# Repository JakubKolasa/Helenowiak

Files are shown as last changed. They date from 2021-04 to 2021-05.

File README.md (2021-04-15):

# Helenowiak
Projekt zakłada stworzenie robota od podstaw. Logika robota będzie oparta na mikrokontrolerze STM32. Zostanie on umieszczony na zaprojektowanej w programie KiCad płytce PCB. Model robota został zaprojektowany w programie AutoCAD Inventor.  Do detekcji przeciwnika wykorzystane zostaną czujniki zbliżeniowe działające w zakresie podczerwieni. W celu zastosowania bardziej skomplikowanych algorytmów walki i umożliwienia swobodnego poruszania się po dojo, robot zostanie wyposażony w czujniki odbiciowe mające na celu wykryć krawędzie areny, oraz enkodery umożliwiające dokładny pomiar przebytej odległości. Robot będzie komunikował się z komputerem poprzez moduł bluetooth dzięki czemu będzie można sterować nim w sposób zdalny przy pomocy odpowiednich komend.

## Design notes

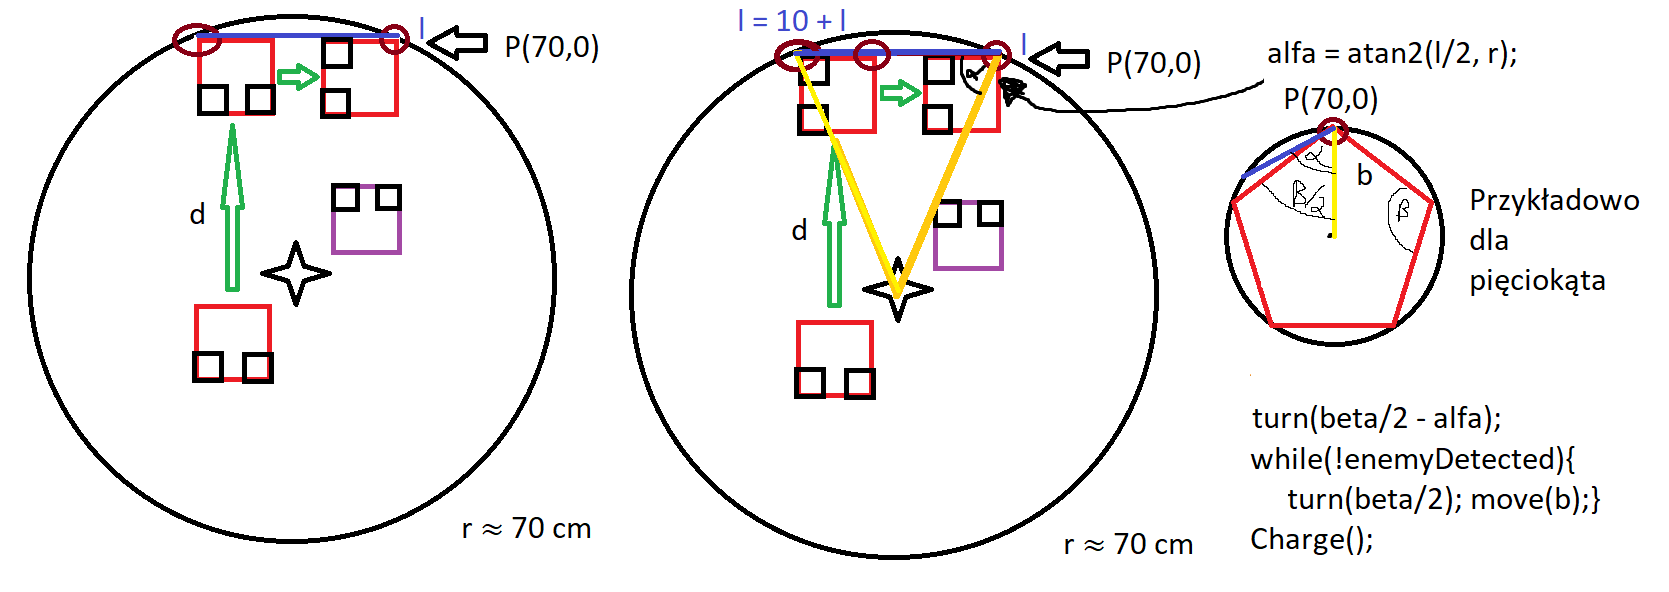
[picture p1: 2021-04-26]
Algorytm.png

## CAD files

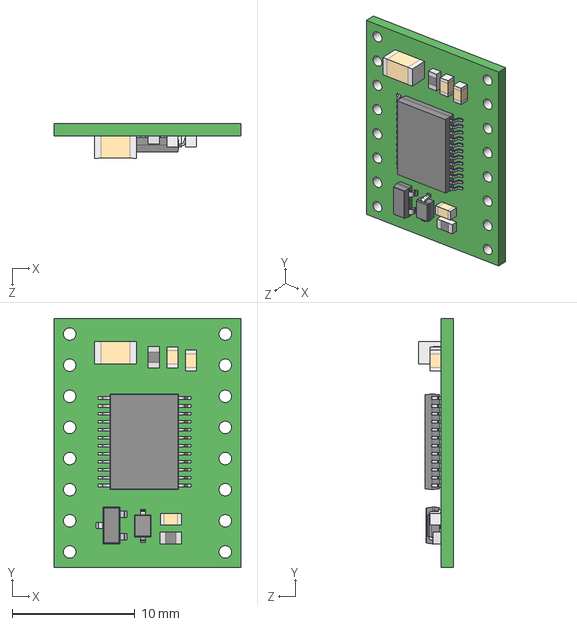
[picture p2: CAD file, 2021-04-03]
Helenowiak_mechanika/tb6612fng-dual-motor-driver-carrier.step
15.2 x 20.3 x 2.82 mm

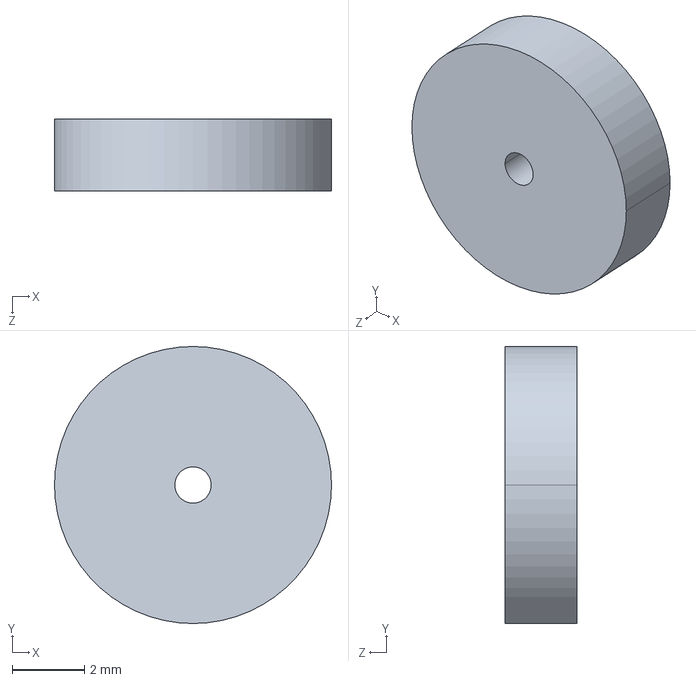
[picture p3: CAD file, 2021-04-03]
Helenowiak_mechanika/magnetic-encoder-pair-kit-for-micro-metal-gearmotors-hpcb-compatible-w1r02a.step
7.65 x 7.65 x 2.00 mm

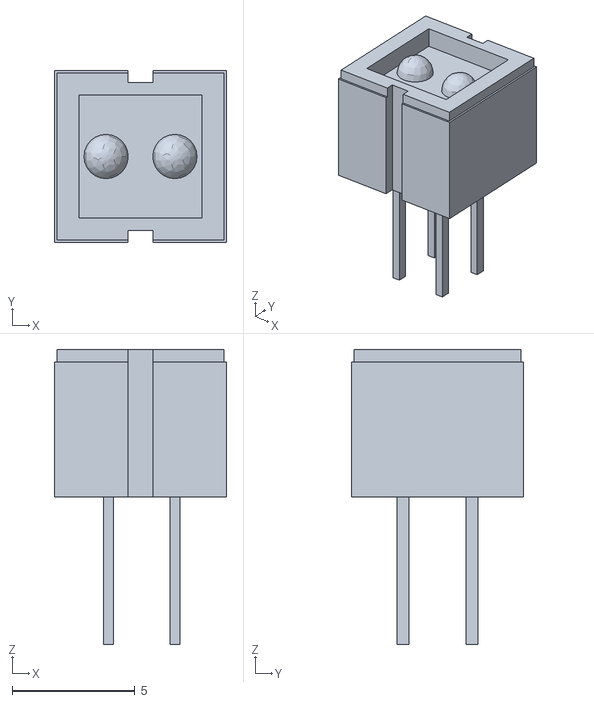
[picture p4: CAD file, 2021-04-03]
Helenowiak_mechanika/cny70.stl
7.00 x 7.00 x 12.0

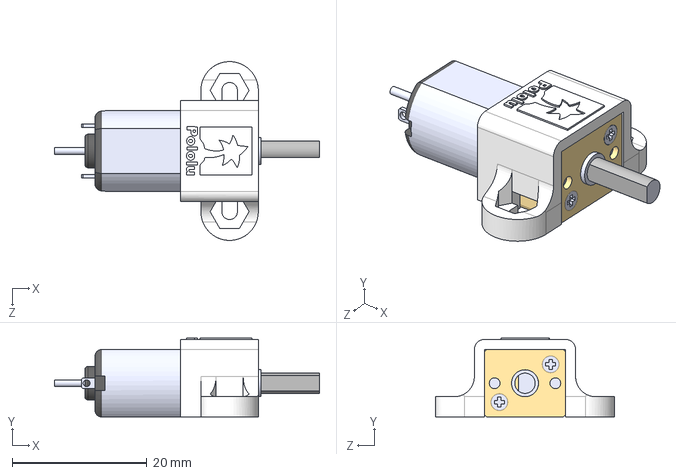
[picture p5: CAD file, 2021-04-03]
Helenowiak_mechanika/micro-metal-gearmotor-extended-with-1086-bracket.step
39.3 x 11.7 x 26.5 mm

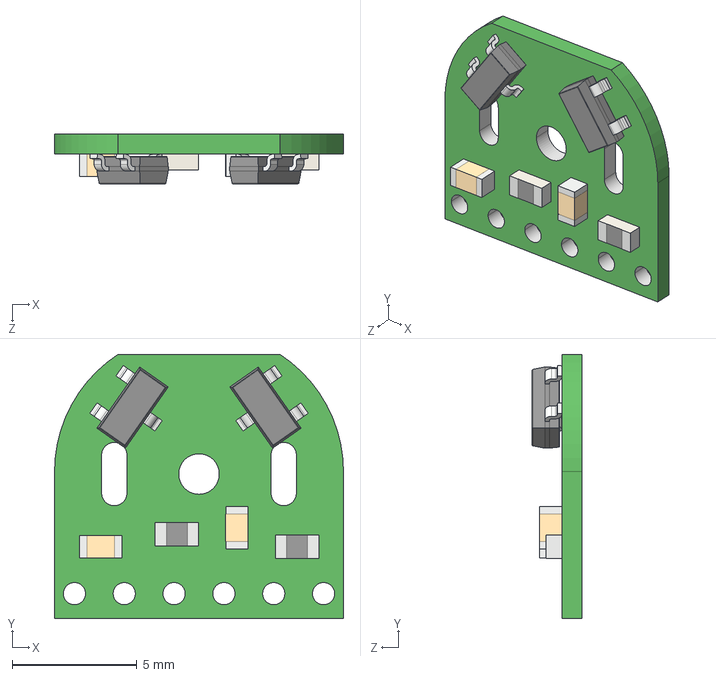
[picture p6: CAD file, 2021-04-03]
Helenowiak_mechanika/magnetic-encoder-pair-kit-for-micro-metal-gearmotors-hpcb-compatible-enc03b.step
11.6 x 10.6 x 1.99 mm

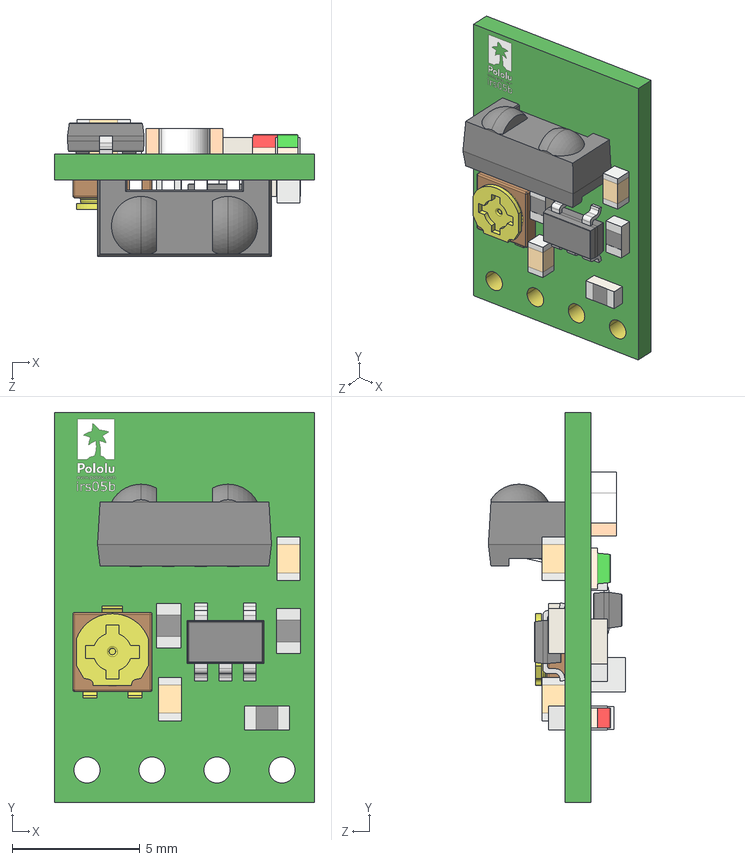
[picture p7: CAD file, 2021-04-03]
Helenowiak_mechanika/pololu-38-khz-ir-proximity-sensor.step
10.2 x 15.2 x 5.37 mm

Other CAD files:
Helenowiak_mechanika/Helenowiak.iam
Helenowiak_mechanika/Helenowiak_plug.ipt
Helenowiak_mechanika/Helenowiak_podpora.ipt
Helenowiak_mechanika/Helenowiak_podstawa.ipt
Helenowiak_mechanika/Helenowiak_polka.ipt
Helenowiak_mechanika/Helenowiak_sciana.ipt
Helenowiak_mechanika/Kolo_Pololu1127.ipt
Helenowiak_mechanika/LiPol.ipt
Helenowiak_mechanika/OldVersions/Część2.0004.ipt
Helenowiak_mechanika/OldVersions/Helenowiak.0027.iam
Helenowiak_mechanika/OldVersions/Helenowiak_korpus.0005.ipt
Helenowiak_mechanika/OldVersions/Helenowiak_pelnyrobot.0006.iam
Helenowiak_mechanika/OldVersions/Helenowiak_plug.0007.ipt
Helenowiak_mechanika/OldVersions/Helenowiak_podpora.0003.ipt
Helenowiak_mechanika/OldVersions/Helenowiak_podstawa.0007.ipt
Helenowiak_mechanika/OldVersions/Helenowiak_polka.0003.ipt
Helenowiak_mechanika/OldVersions/Helenowiak_sciana.0004.ipt
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

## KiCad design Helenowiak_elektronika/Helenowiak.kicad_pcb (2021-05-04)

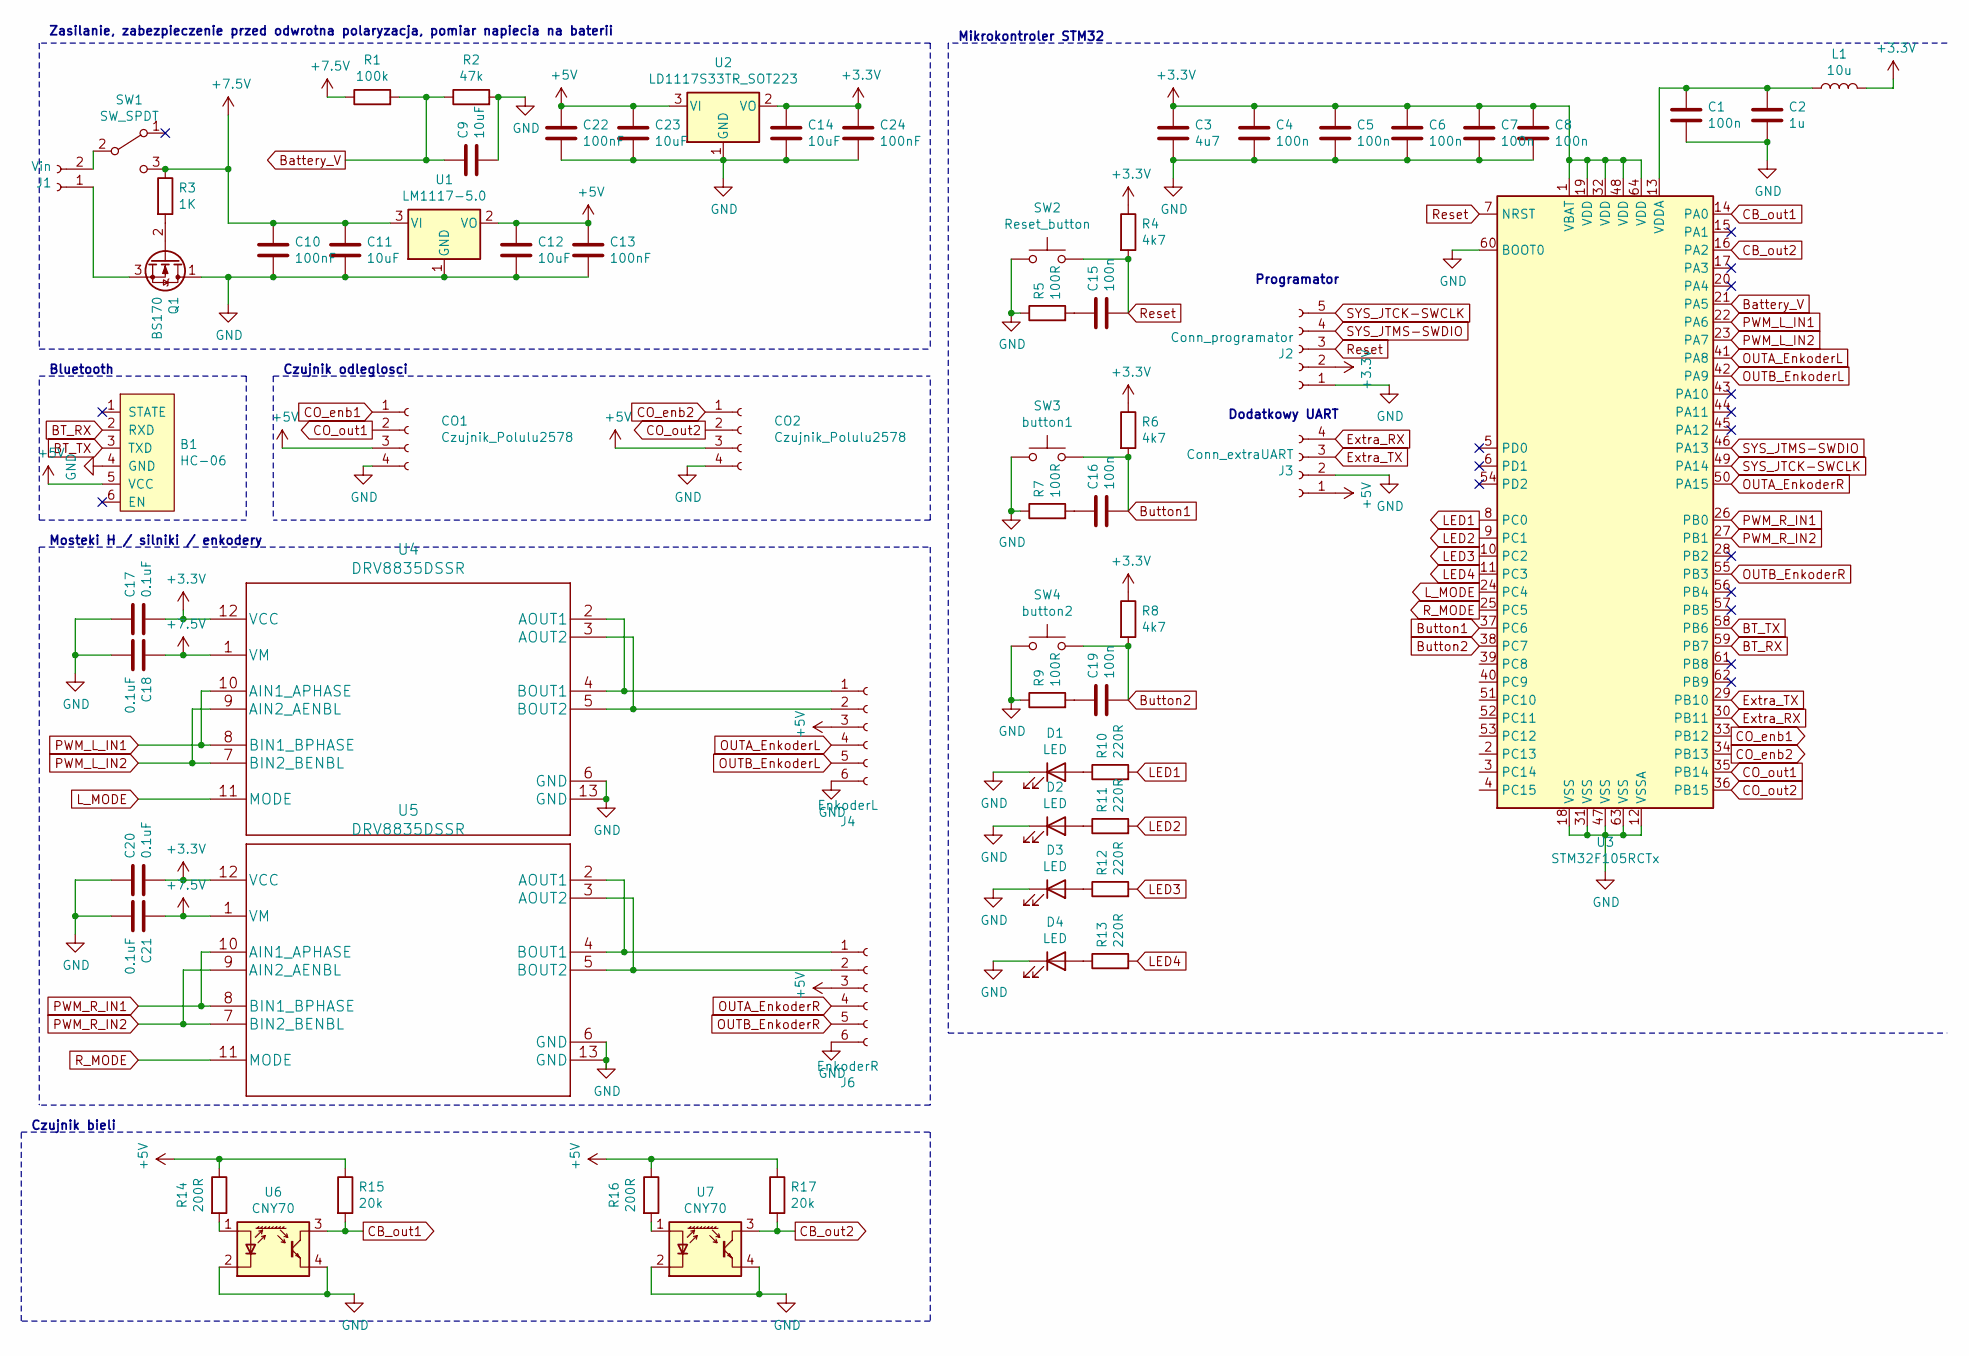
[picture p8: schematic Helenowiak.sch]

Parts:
B1: HC-06; PinSocket_1x06_P2.54mm_Vertical
C1, C4, C5, C6, C7, C8, C15, C16, C19: 100n; C_0603
C2: 1u; C_0603
C3: 4u7; C_0603
C9, C11, C12, C14, C23: 10uF; C_0603
C10, C13, C22, C24: 100nF; C_0603
C17, C18, C20, C21: 0.1uF; C_0603
CO1, CO2: Czujnik_Polulu2578; PinSocket_1x04_P2.54mm_Vertical
D1, D2, D3, D4: LED; LED_0603_1608Metric
J1: Vin; PinSocket_1x02_P2.54mm_Vertical
J2: Conn_programator; PinSocket_1x05_P2.54mm_Vertical
J3: Conn_extraUART; PinSocket_1x04_P2.54mm_Vertical
J4: EnkoderL; PinSocket_1x06_P2.54mm_Vertical
J6: EnkoderR; PinSocket_1x06_P2.54mm_Vertical
L1: 10u; L_0603
Q1: BS170; TO-92_Inline
R1: 100k; R_0603_1608Metric
R2: 47k; R_0603_1608Metric
R3: 1K; R_0603_1608Metric
R4, R6, R8: 4k7; R_0603_1608Metric
R5, R7, R9: 100R; R_0603_1608Metric
R10, R11, R12, R13: 220R; R_0603_1608Metric
R14, R16: 200R; R_0603_1608Metric
R15, R17: 20k; R_0603_1608Metric
SW1: SW_SPDT; PinSocket_1x03_P2.54mm_Vertical
SW2: Reset_button; button_mono
SW3: button1; button_mono
SW4: button2; button_mono
U1: LM1117-5.0; TO-220-3_Vertical
U2: LD1117S33TR_SOT223; SOT-223-3_TabPin2
U3: STM32F105RCTx; LQFP-64_10x10mm_P0.5mm
U4: DRV8835DSSR; WSON-12-1EP_3x2mm_Pitch0.5mm
U5: DRV8835DSSR; WSON-12-1EP_3x2mm_P0.5mm_EP1x2.65
U6, U7: CNY70; Vishay_CNY70

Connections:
+3V3: C3.1, C4.1, C5.1, C6.1, C7.1, C8.1, C14.1, C17.2, C20.2, C24.1, J2.2, L1.2, R4.1, R6.1, R8.1, U2.2 (VO), U3.1 (VBAT), U3.19 (VDD), U3.32 (VDD), U3.48 (VDD), U3.64 (VDD), U4.12 (VCC), U5.12 (VCC)
+5V: B1.5 (VCC), C12.1, C13.1, C22.1, C23.1, CO1.3, CO2.3, J3.1, J4.3, J6.3, R14.1, R15.1, R16.1, R17.1, U1.2 (VO), U2.3 (VI)
+7.5V: C10.1, C11.1, C18.1, C21.1, R1.1, R3.1, SW1.3 (C), U1.3 (VI), U4.1 (VM), U5.1 (VM)
BT_RX: B1.2 (RXD), U3.59 (PB7)
BT_TX: B1.3 (TXD), U3.58 (PB6)
Battery_V: C9.1, R1.2, R2.1, U3.21 (PA5)
Button1: C16.2, R6.2, SW3.2, U3.37 (PC6)
Button2: C19.2, R8.2, SW4.2, U3.38 (PC7)
CB_out1: R15.2, U3.14 (PA0), U6.3 (C)
CB_out2: R17.2, U3.16 (PA2), U7.3 (C)
CO_enb1: CO1.1, U3.33 (PB12)
CO_enb2: CO2.1, U3.34 (PB13)
CO_out1: CO1.2, U3.35 (PB14)
CO_out2: CO2.2, U3.36 (PB15)
Extra_RX: J3.4, U3.30 (PB11)
Extra_TX: J3.3, U3.29 (PB10)
GND: B1.4 (GND), C1.2, C2.2, C3.2, C4.2, C5.2, C6.2, C7.2, C8.2, C9.2, C10.2, C11.2, C12.2, C13.2, C14.2, C17.1, C18.2, C20.1, C21.2, C22.2, C23.2, C24.2, CO1.4, CO2.4, D1.1 (K), D2.1 (K), D3.1 (K), D4.1 (K), J2.1, J3.2, J4.6, J6.6, Q1.1 (D), R2.2, R5.1, R7.1, R9.1, SW2.1, SW3.1, SW4.1, U1.1 (GND), U2.1 (GND), U3.12 (VSSA), U3.18 (VSS), U3.31 (VSS), U3.47 (VSS), U3.60 (BOOT0), U3.63 (VSS), U4.6 (GND), U4.13 (GND), U5.6 (GND), U5.13 (GND), U6.2 (K), U6.4 (E), U7.2 (K), U7.4 (E)
LED1: R10.2, U3.8 (PC0)
LED2: R11.2, U3.9 (PC1)
LED3: R12.2, U3.10 (PC2)
LED4: R13.2, U3.11 (PC3)
L_MODE: U3.24 (PC4), U4.11 (MODE)
unnamed: C1.1, C2.1, L1.1, U3.13 (VDDA)
unnamed: C15.1, R5.2
unnamed: C16.1, R7.2
unnamed: C19.1, R9.2
unnamed: D1.2 (A), R10.1
unnamed: D2.2 (A), R11.1
unnamed: D3.2 (A), R12.1
unnamed: D4.2 (A), R13.1
unnamed: J1.1, Q1.3 (S)
unnamed: J1.2, SW1.2 (B)
unnamed: J4.1, U4.2 (AOUT1), U4.4 (BOUT1)
unnamed: J4.2, U4.3 (AOUT2), U4.5 (BOUT2)
unnamed: J6.1, U5.2 (AOUT1), U5.4 (BOUT1)
unnamed: J6.2, U5.3 (AOUT2), U5.5 (BOUT2)
unnamed: Q1.2 (G), R3.2
unnamed: R14.2, U6.1 (A)
unnamed: R16.2, U7.1 (A)
OUTA_EnkoderL: J4.4, U3.41 (PA8)
OUTA_EnkoderR: J6.4, U3.50 (PA15)
OUTB_EnkoderL: J4.5, U3.42 (PA9)
OUTB_EnkoderR: J6.5, U3.55 (PB3)
PWM_L_IN1: U3.22 (PA6), U4.8 (BIN1_BPHASE), U4.10 (AIN1_APHASE)
PWM_L_IN2: U3.23 (PA7), U4.7 (BIN2_BENBL), U4.9 (AIN2_AENBL)
PWM_R_IN1: U3.26 (PB0), U5.8 (BIN1_BPHASE), U5.10 (AIN1_APHASE)
PWM_R_IN2: U3.27 (PB1), U5.7 (BIN2_BENBL), U5.9 (AIN2_AENBL)
R_MODE: U3.25 (PC5), U5.11 (MODE)
Reset: C15.2, J2.3, R4.2, SW2.2, U3.7 (NRST)
SYS_JTCK-SWCLK: J2.5, U3.49 (PA14)
SYS_JTMS-SWDIO: J2.4, U3.46 (PA13)

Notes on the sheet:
Czujnik odleglosci
Czujnik bieli
Bluetooth
Mosteki H / silniki / enkodery
Mikrokontroler STM32
Zasilanie, zabezpieczenie przed odwrotna polaryzacja, pomiar napiecia na baterii
Programator
Dodatkowy UART

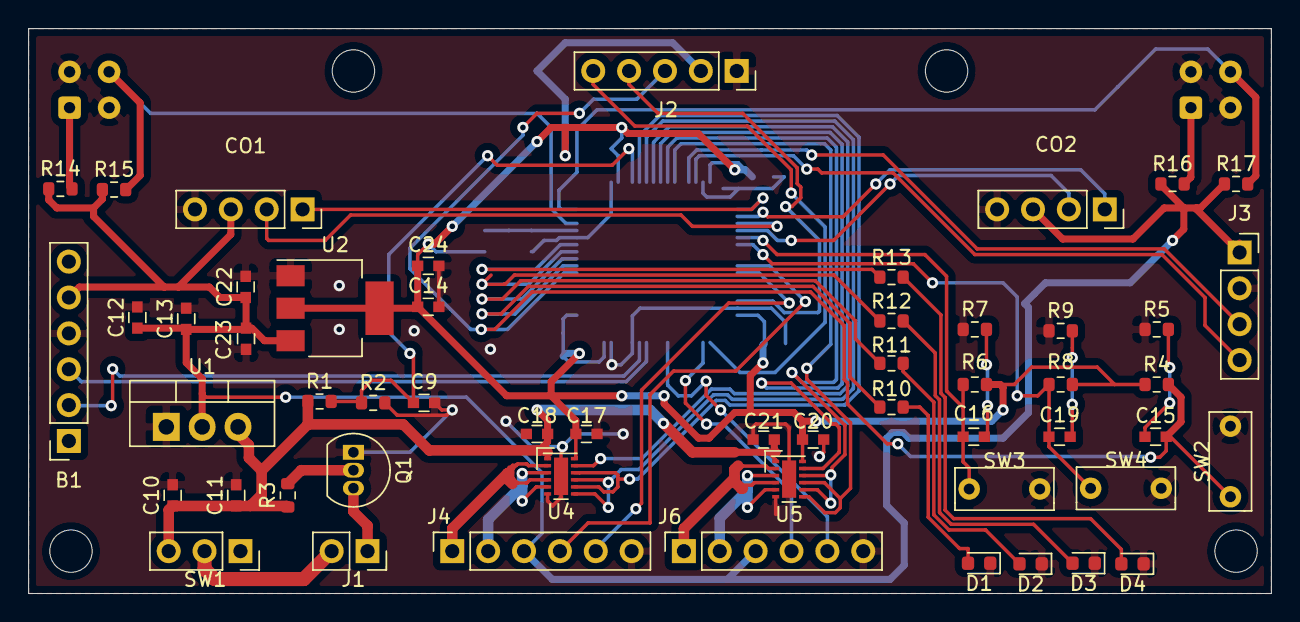
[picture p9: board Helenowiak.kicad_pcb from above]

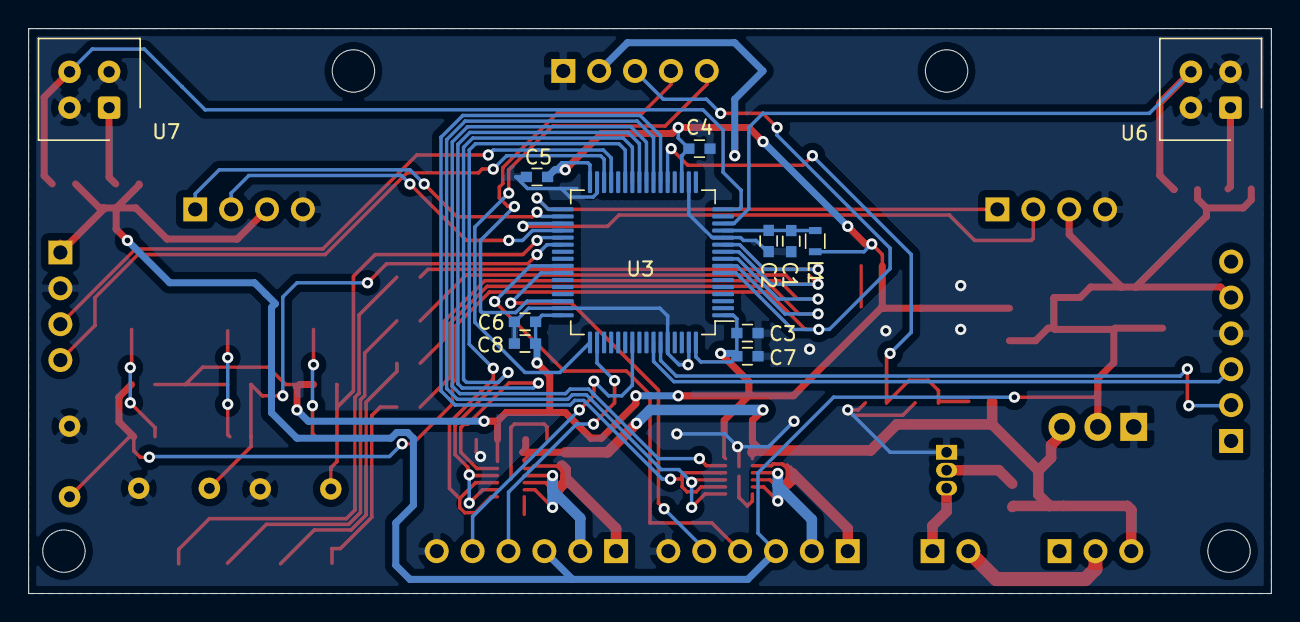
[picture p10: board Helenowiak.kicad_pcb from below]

Board: 2 copper layers, 88.0 x 40.0 mm, 66 parts (12 on the bottom side), 51 nets.

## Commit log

2021-03-17 Pierwszy commit, poczatki projektowania elektroniki
    [Helenowiak.kicad_pcb, Helenowiak.sch]
2021-03-18 Wszystko oprocz stm32
    [Helenowiak.sch]
2021-04-03 Mechanika prawie gotowa, elektronika brak stm32
    [Część2.0004.ipt, Helenowiak.0023.iam, Helenowiak.iam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]
2021-04-15 New stm32
    [Helenowiak.sch]
2021-04-20 New pinout
    [Helenowiak.sch]
2021-04-21 Finished eschema
    [Helenowiak.sch]
2021-04-25 Etap II
    [Helenowiak.0023.iam, Helenowiak.0024.iam, Helenowiak.iam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]
2021-04-26 Dodana prezentacja algorytmu
    [Helenowiak.0024.iam, Helenowiak.0025.iam, Helenowiak.iam]
2021-05-02 PCB 75%
    [Helenowiak.0025.iam, Helenowiak.0027.iam, Helenowiak.iam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]
2021-05-04 Przed wylaniem masy
    [Helenowiak.kicad_pcb, Helenowiak.sch]
2021-05-04 PCB zamowione
    [Helenowiak.kicad_pcb, Helenowiak.sch]
